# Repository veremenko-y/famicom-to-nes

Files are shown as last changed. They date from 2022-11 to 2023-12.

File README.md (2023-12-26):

# Famicom to NES adapter

Adapter from Famicom to NES.

CIC replica chip firmware can be found at [krizz/avrciczz](https://github.com/krikzz/avrciczz).

## PCB Warning

**Board thickness must be 1.2mm**, not standard 1.6mm. **Boards over 1.2mm will damage NES ZIF cartridge socket.**

**I have not personally tested the board, [but another github user did](https://github.com/veremenko-y/famicom-to-nes/issues/1#issuecomment-1863692287)**

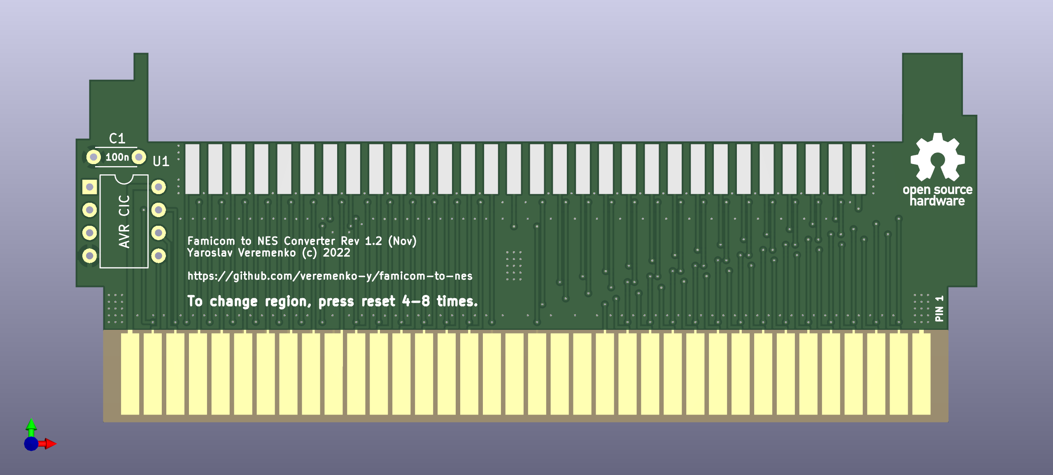
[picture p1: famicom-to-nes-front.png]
famicom-to-nes-front

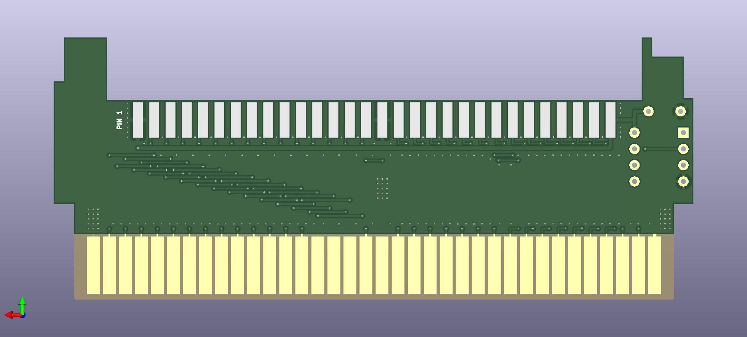
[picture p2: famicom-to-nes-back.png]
famicom-to-nes-back


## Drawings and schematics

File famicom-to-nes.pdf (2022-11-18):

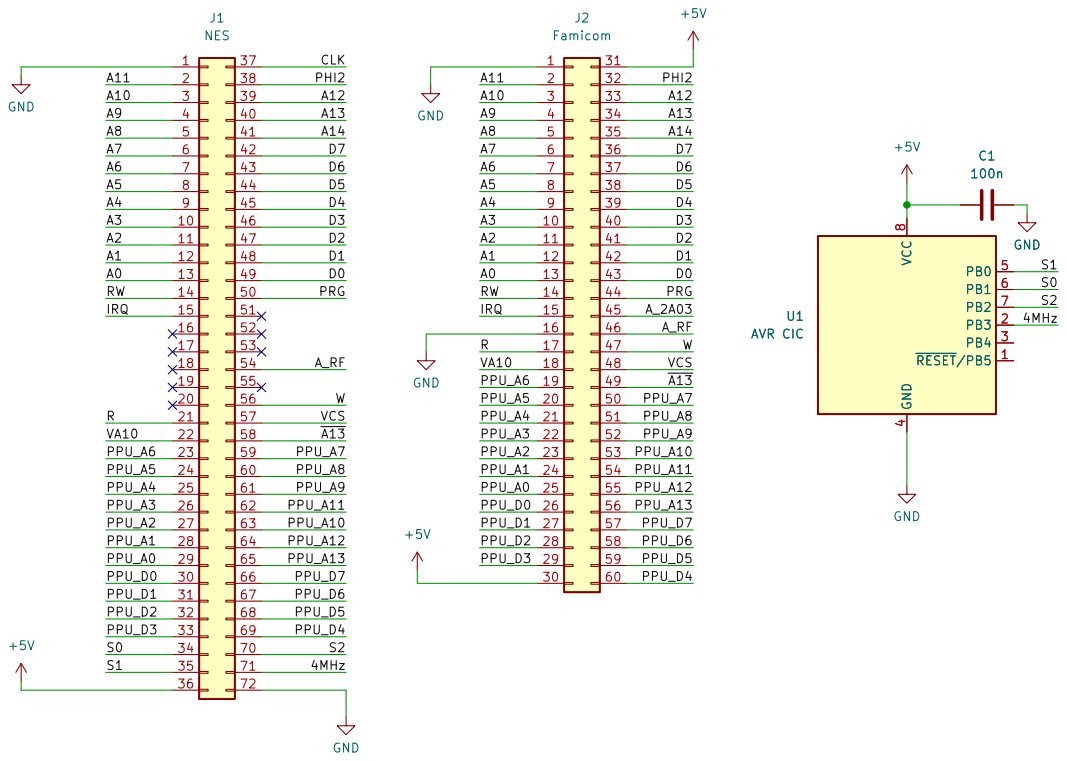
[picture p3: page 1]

65 | 29
66 | 30

File: famicom-to-nes.kicad_sch Sheet: / Yaroslav Veremenko

Id: 1/1 Title: Famicom to NES Adapter

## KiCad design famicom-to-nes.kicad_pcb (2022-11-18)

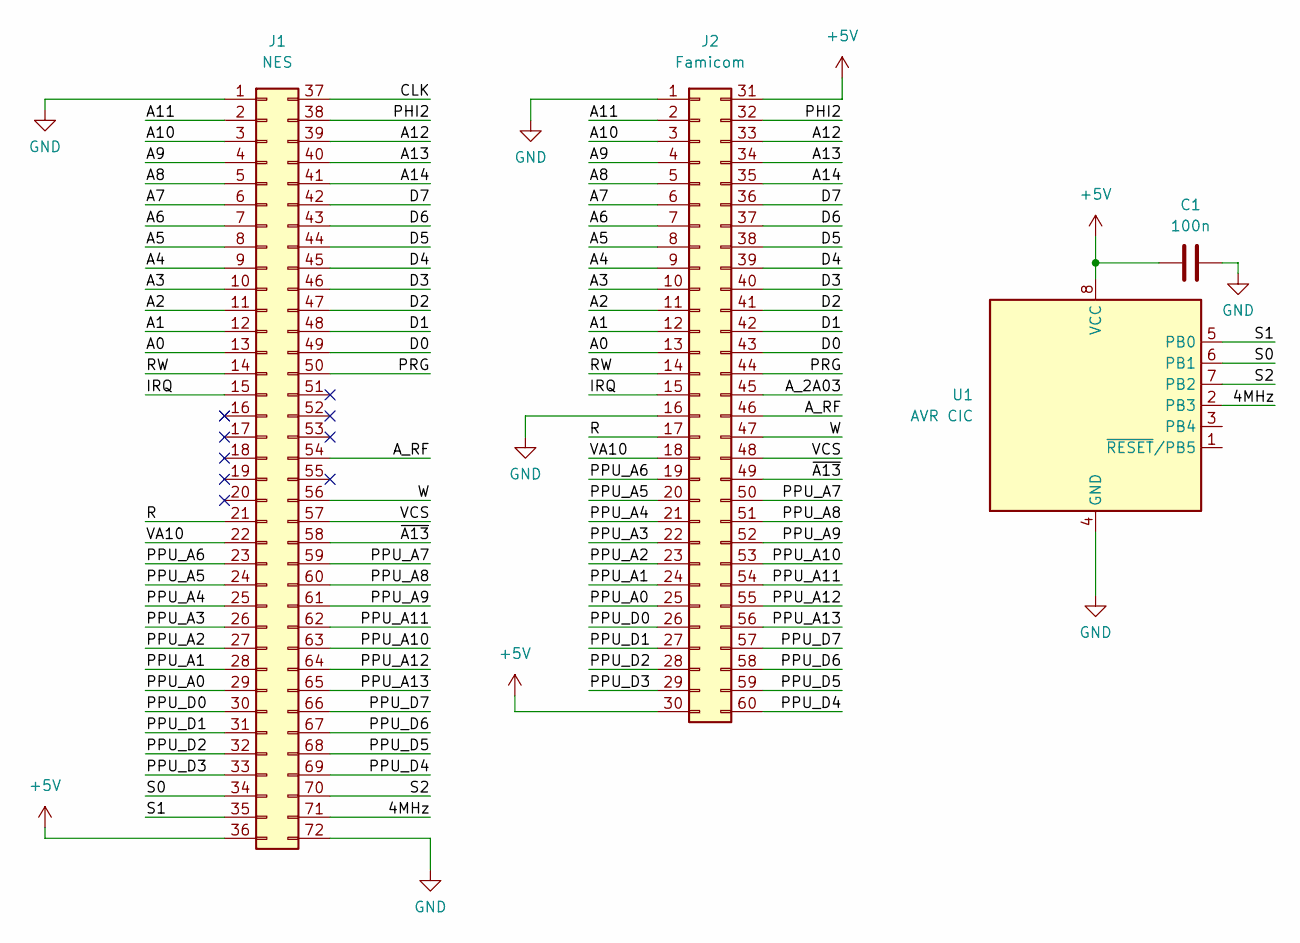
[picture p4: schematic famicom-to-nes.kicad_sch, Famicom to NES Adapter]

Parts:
C1: 100n; C_Disc_D4.3mm_W1.9mm_P5.00mm
J1: NES; NES_Cart_Edge_Connector
J2: Famicom; Famicom-60SocketEdge
U1: AVR CIC; DIP-8_W7.62mm

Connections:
+5V: C1.1, J1.36, J2.30, J2.31, U1.8 (VCC)
/4MHz: J1.71, U1.2 (PB3)
/A0: J1.13, J2.13
/A1: J1.12, J2.12
/A2: J1.11, J2.11
/A3: J1.10, J2.10
/A4: J1.9, J2.9
/A5: J1.8, J2.8
/A6: J1.7, J2.7
/A7: J1.6, J2.6
/A8: J1.5, J2.5
/A9: J1.4, J2.4
/A10: J1.3, J2.3
/A11: J1.2, J2.2
/A12: J1.39, J2.33
/A13: J1.40, J2.34
/A14: J1.41, J2.35
/A_2A03: J2.45
/A_RF: J1.54, J2.46
/CLK: J1.37
/D0: J1.49, J2.43
/D1: J1.48, J2.42
/D2: J1.47, J2.41
/D3: J1.46, J2.40
/D4: J1.45, J2.39
/D5: J1.44, J2.38
/D6: J1.43, J2.37
/D7: J1.42, J2.36
/IRQ: J1.15, J2.15
/PHI2: J1.38, J2.32
/PPU_A0: J1.29, J2.25
/PPU_A1: J1.28, J2.24
/PPU_A2: J1.27, J2.23
/PPU_A3: J1.26, J2.22
/PPU_A4: J1.25, J2.21
/PPU_A5: J1.24, J2.20
/PPU_A6: J1.23, J2.19
/PPU_A7: J1.59, J2.50
/PPU_A8: J1.60, J2.51
/PPU_A9: J1.61, J2.52
/PPU_A10: J1.63, J2.53
/PPU_A11: J1.62, J2.54
/PPU_A12: J1.64, J2.55
/PPU_A13: J1.65, J2.56
/PPU_D0: J1.30, J2.26
/PPU_D1: J1.31, J2.27
/PPU_D2: J1.32, J2.28
/PPU_D3: J1.33, J2.29
/PPU_D4: J1.69, J2.60
/PPU_D5: J1.68, J2.59
/PPU_D6: J1.67, J2.58
/PPU_D7: J1.66, J2.57
/PRG: J1.50, J2.44
/R: J1.21, J2.17
/RW: J1.14, J2.14
/S0: J1.34, U1.6 (PB1)
/S1: J1.35, U1.5 (PB0)
/S2: J1.70, U1.7 (PB2)
/VA10: J1.22, J2.18
/VCS: J1.57, J2.48
/W: J1.56, J2.47
/~A13: J1.58, J2.49
GND: C1.2, J1.1, J1.72, J2.1, J2.16, U1.4 (GND)

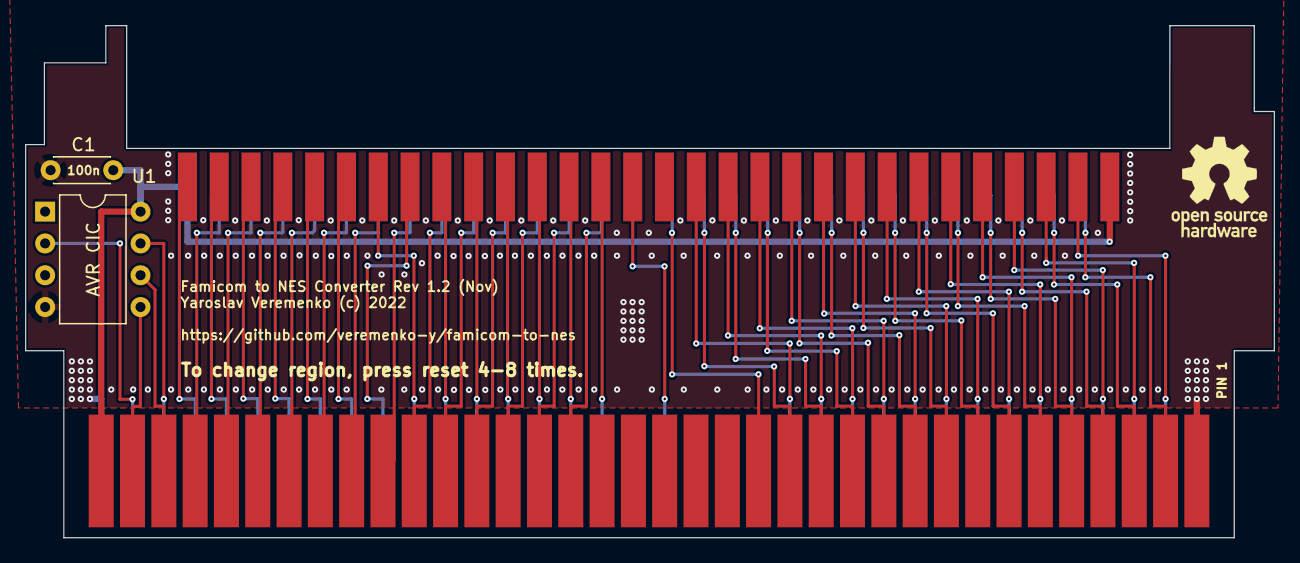
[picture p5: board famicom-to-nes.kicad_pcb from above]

Board: 2 copper layers, 99.7 x 40.9 mm, 4 parts (1 on the bottom side), 61 nets.

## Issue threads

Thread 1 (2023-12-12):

the U1 name?

hualazimo7, 2023-12-12:
I see AVR CIC on the pcb, which chip should I use?
☺

veremenko-y, 2023-12-12:
IC is ATTiny13, you can find firmware here: https://github.com/krikzz/avrciczz it's avrciczz project.

FYI I made the boards, but still haven't tested it. On the first iteration, I made 1.6mm pcb, and it was a mistake. Make sure you order 1.2mm.

1.6 is too thick for NES ZIF socket.

veremenko-y, 2023-12-12:
Updated README.md as well.

hualazimo7, 2023-12-19:
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

1.2mm thickness is perfect.  Test succeeded, thanks.

veremenko-y, 2023-12-20:
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

Did you make one and it worked for you?

hualazimo7, 2023-12-20:
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

Yes, It worked on my Retroad console, a third-party product,  just like NES.
the console needs resetting  6-8 times indeed.

Closed 2023-12-12.

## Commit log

2022-11-17 Initial commit Rev 1.1
    [famicom-to-nes.kicad_pcb, famicom-to-nes.kicad_sch]
2022-11-18 Rev 1.2
    [famicom-to-nes.kicad_pcb, famicom-to-nes.kicad_sch]

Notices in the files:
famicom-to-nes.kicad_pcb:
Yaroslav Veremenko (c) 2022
